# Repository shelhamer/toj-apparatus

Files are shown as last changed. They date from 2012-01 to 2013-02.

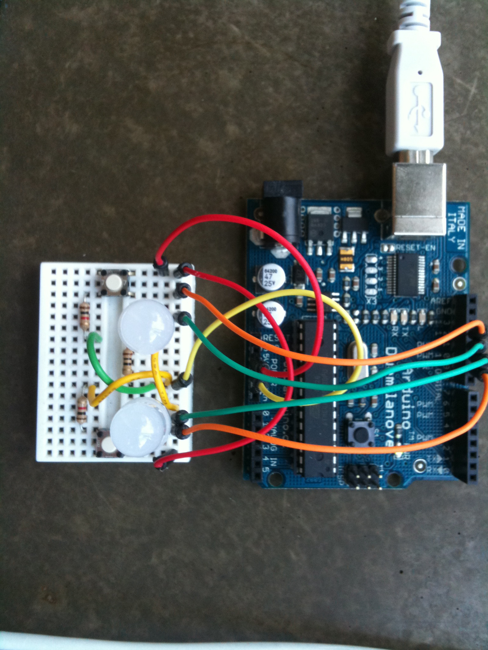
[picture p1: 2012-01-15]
toj-apparatus-top.jpg

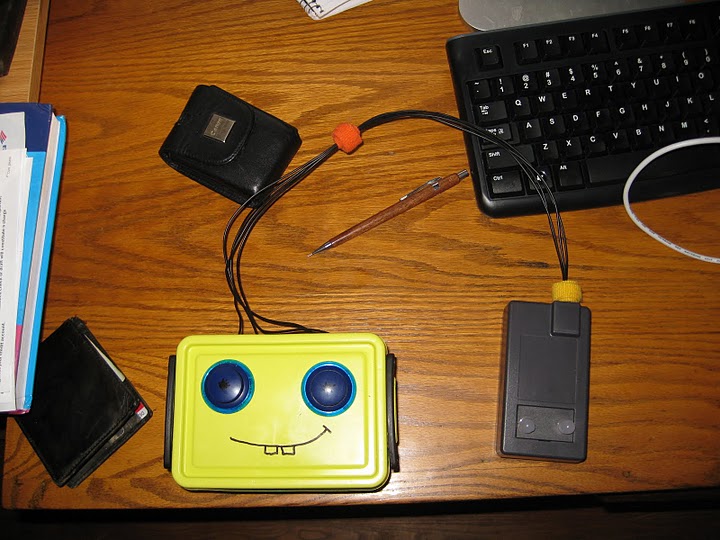
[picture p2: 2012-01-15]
toj-apparatus-case.jpg

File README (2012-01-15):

Time Order Judgement (TOJ) Apparatus & Controller

A novel apparatus for presenting visual light pulses and recording time order
judgements with subject response time. ~1 millisecond precision in both light
presentation and response time measurement. Assembled with simple electronic
components on a breadboard connected to an Arduino Duemilanove, programmed in
Arduino, and interfaced to a computer via serial to a Processing app.

Time order judgements concern the evaluation and decision of the relative
ordering of a series of events. In this case, the apparatus has two diffuse
white LEDs that can be pulsed with precision of < 1 ms. Five types of pulse
pairs are possible:

*  >  * left on, right on, left off, right off
* --> * left on, left off, right on, right off
*  <  * the first with direction reversed
* <-- * the second with direction reversed
*  =  * both on on simultaneously

The delay between the onset of one pulse after the other is determined by
pulse pair definitions which are triggered by the apparatus controller running
on a computer.

The apparatus is necessary because the careful presentation of stimuli in time
is complicated by computer monitor refresh rates and time resolution is
inadequate for the short delays tested in time order judgement experiments.

Within a certain time threshold, an observer will see a sequence of two
pulses as one single, simultaneous pulse. This is similar to the echo threshold
and precedence effect in psychoacoustics: if the same sound signal arrives at
an observer at different times within a certain window, only the direction of
the first arrival is perceived. The curious can read more here:

http://murphylibrary.uwlax.edu/digital/journals/JASA/JASA1999/pdfs/vol_106/iss_4/1633_1.pdf

The apparatus and controller were designed, assembled, and programmed by Evan
Shelhamer. The idea for the apparatus and the specific experimental stimuli
light pulse patterns are due to Patrick Taylor, PhD student in the neuroscience
and behavior and cognitive divisions of UMass Amherst Psychology.

TimeOrderApparatus: arduino project for running the device itself. Presents
visual flashes through LEDs, accepts push button responses, and communicates
over serial.

TimeOrderController: processing.org project for running experiments with the
apparatus. Reads stimulus sequence files, commands the apparatus, and
records responses and reaction times collected from apparatus to CSV.

Refer to photos for an idea of its construction. A bill of materials and
circuit diagram will be included once prepared.

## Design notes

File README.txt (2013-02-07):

Time Order Judgement (TOJ) Apparatus & Controller

A novel apparatus for presenting visual light pulses and recording time order
judgements with subject response time. ~1 millisecond precision in both light
presentation and response time measurement. Assembled with simple electronic
components on a breadboard connected to an Arduino Duemilanove, programmed in
Arduino, and interfaced to a computer via serial to a Processing app.

Time order judgements concern the evaluation and decision of the relative
ordering of a series of events. In this case, the apparatus has two diffuse
white LEDs that can be pulsed with precision of < 1 ms. Five types of pulse
pairs are possible:

*  >  * left on, right on, left off, right off
* --> * left on, left off, right on, right off
*  <  * the first with direction reversed
* <-- * the second with direction reversed
*  =  * both on on simultaneously

The delay between the onset of one pulse after the other is determined by
pulse pair definitions which are triggered by the apparatus controller running
on a computer.

The apparatus is necessary because the careful presentation of stimuli in time
is complicated by computer monitor refresh rates and time resolution is
inadequate for the short delays tested in time order judgement experiments.

Within a certain time threshold, an observer will see a sequence of two
pulses as one single, simultaneous pulse. This is similar to the echo threshold
and precedence effect in psychoacoustics: if the same sound signal arrives at
an observer at different times within a certain window, only the direction of
the first arrival is perceived. The curious can read more here:

http://murphylibrary.uwlax.edu/digital/journals/JASA/JASA1999/pdfs/vol_106/iss_4/1633_1.pdf

The apparatus and controller were designed, assembled, and programmed by Evan
Shelhamer. The idea for the apparatus and the specific experimental stimuli
light pulse patterns are due to Patrick Taylor, PhD student in the neuroscience
and behavior and cognitive divisions of UMass Amherst Psychology.

TimeOrderApparatus: arduino project for running the device itself. Presents
visual flashes through LEDs, accepts push button responses, and communicates
over serial.

TimeOrderController: processing.org project for running experiments with the
apparatus. Reads stimulus sequence files, commands the apparatus, and
records responses and reaction times collected from apparatus to CSV.

To make your own:

- Check the bill of materials.
- Consult the schematic and breadboard images for wiring.
- Refer to photos for an idea of its construction.
- Install the Arduino toolkit to load the software to the device.
- Install the Processing.org toolkit to run the experiment controller.

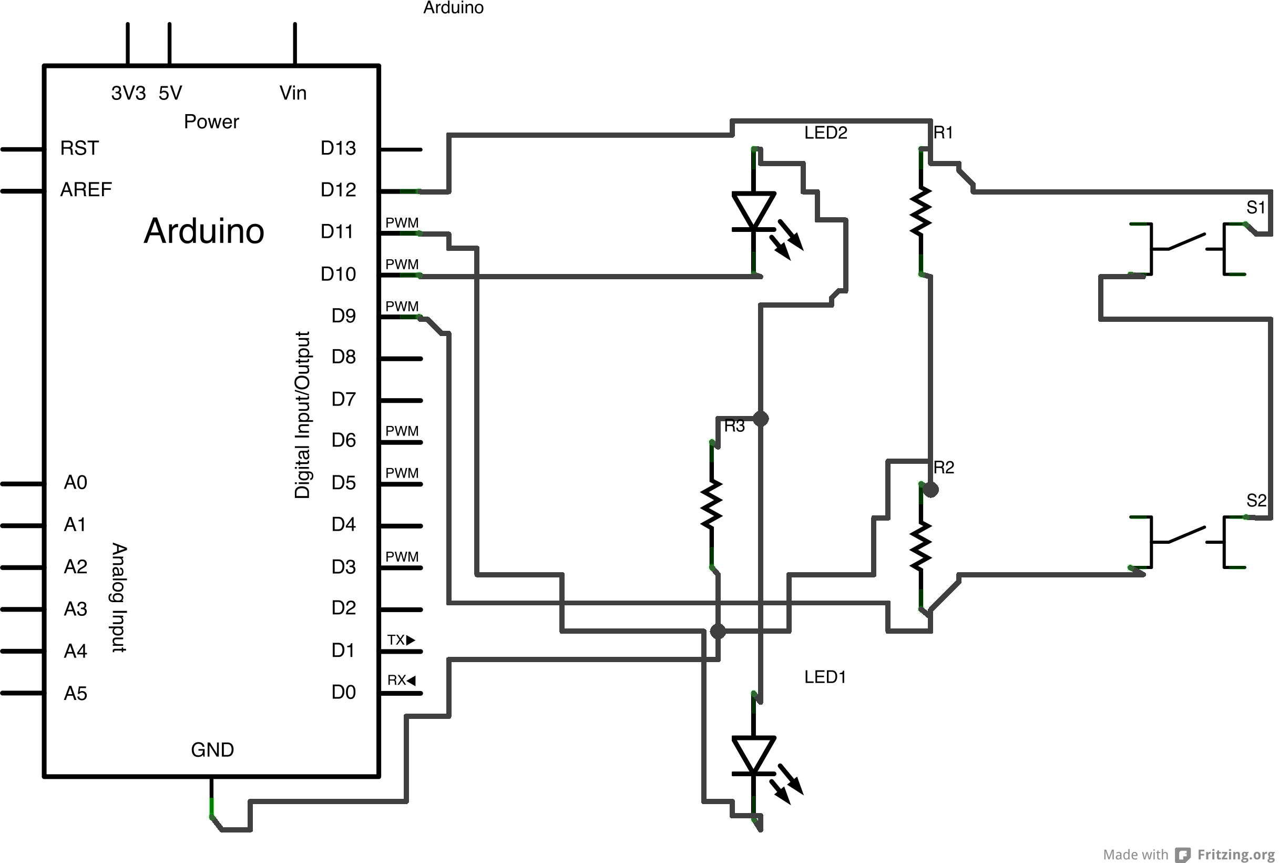
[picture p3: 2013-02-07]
schematic.png

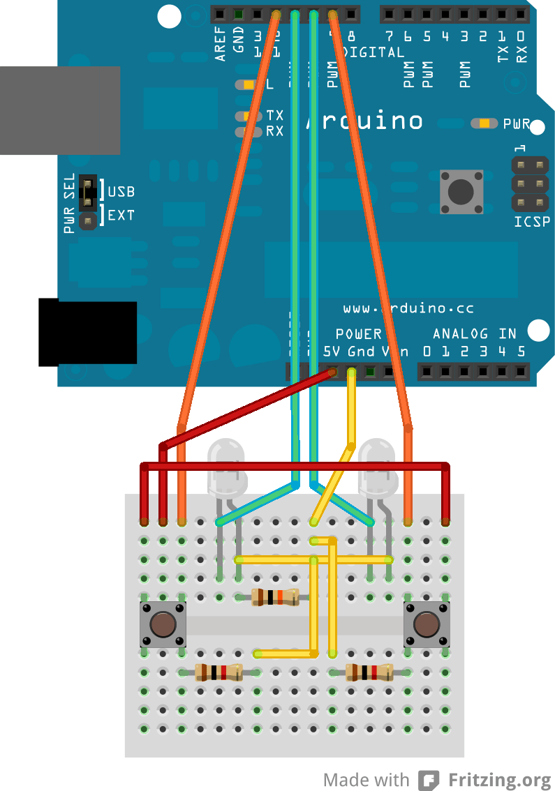
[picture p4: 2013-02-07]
breadboard.png

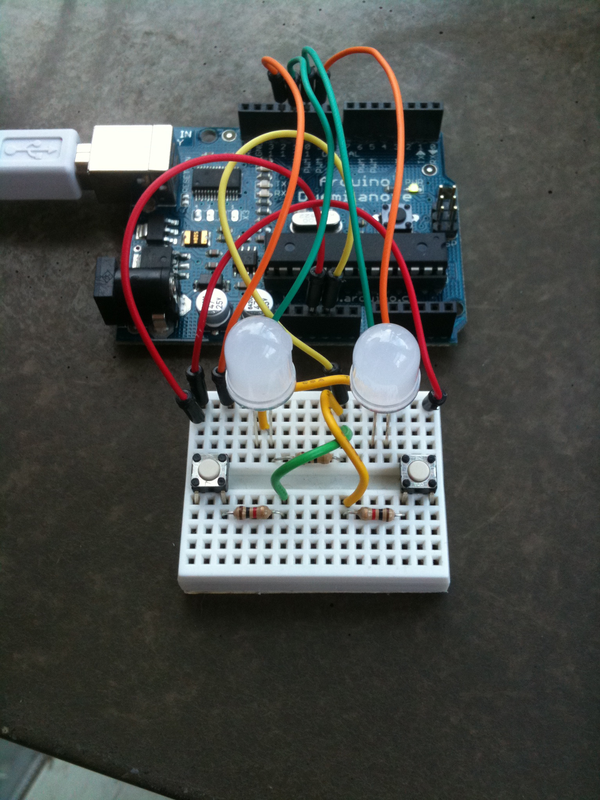
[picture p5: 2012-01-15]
toj-apparatus.jpg

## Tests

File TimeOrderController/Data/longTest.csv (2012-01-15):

Pulse | Side | ReactionTime
00 | L | 1056
15 | L | 600
15 | R | 1066
04 | L | 700
00 | R | 684
00 | R | 537
00 | R | 1011
15 | R | 471
19 | R | 1010
00 | R | 1204
15 | R | 724
15 | L | 1014
15 | R | 814
00 | R | 1569
15 | R | 918
00 | R | 458
04 | R | 471
19 | R | 494
04 | R | 660
19 | R | 458
15 | L | 1328
00 | R | 719
15 | R | 1408
15 | L | 733
15 | R | 897
00 | R | 1099
04 | R | 628
19 | R | 1546
00 | R | 915
00 | L | 857
00 | L | 593
15 | L | 1270
15 | L | 748
19 | R | 1215
04 | L | 498
15 | L | 662
15 | R | 722
00 | R | 1134
15 | R | 909
04 | R | 674
00 | L | 815
15 | R | 688

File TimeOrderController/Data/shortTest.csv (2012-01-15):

Pulse | Side | ReactionTime
01 | L | 389
02 | L | 427
09 | L | 397
26 | R | 359
03 | L | 873
08 | L | 705

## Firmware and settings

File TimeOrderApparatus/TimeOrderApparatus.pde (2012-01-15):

/**
 * Time Order Judgement (TOJ) Apparatus
 *
 * Present time light pulses through LEDs, identify button press responses,
 * accepting pulse commands and returning responses over serial.
 * Developed for Patrick Taylor in the NeuroCognition and Perception (NCaP) lab
 * UMass Amherst
 *
 * Evan Shelhamer. Fall '10.
 */

/* CONSTANTS */

// LEDs, left or right
#define LED_L 11
#define LED_R 10

// Buttons
#define BUTTON_R 9
#define BUTTON_L 12

// Duration of LED lighting, total # of pulses, sequence length
#define DUR 15
#define NUM_PULSE 30

// Pulse array indices
#define LED 0
#define DELAY 1

/* PULSE DEFINITIONS */

// Defined as 1st LED to light, and delay until 2nd
// N.B. Pulses defined by Patrick Taylor
long pulses[NUM_PULSE][2] = {
  {LED_L, 3}, //0
  {LED_L, 6}, //1
  {LED_L, 9}, //2
  {LED_L, 12}, //3
  {LED_L, 15}, //4
  {LED_L, 18}, //5
  {LED_L, 21}, //6
  {LED_L, 24}, //7
  {LED_L, 27}, //8
  {LED_L, 30}, //9
  {LED_L, 33}, //10
  {LED_L, 36}, //11
  {LED_L, 39}, //12
  {LED_L, 42}, //13
  {LED_L, 45}, //14
  {LED_R, 3}, //15
  {LED_R, 6}, //16
  {LED_R, 9}, //17
  {LED_R, 12}, //18
  {LED_R, 15}, //19
  {LED_R, 18}, //20
  {LED_R, 21}, //21
  {LED_R, 24}, //22
  {LED_R, 27}, //23
  {LED_R, 30}, //24
  {LED_R, 33}, //25
  {LED_R, 36}, //26
  {LED_R, 39}, //27
  {LED_R, 42}, //28
  {LED_R, 45} //29
};

void setup() {
  // Initialize LED pins to output & off state
  pinMode(LED_L, OUTPUT);
  pinMode(LED_R, OUTPUT);
  digitalWrite(LED_L, LOW);
  digitalWrite(LED_R, LOW);

  // Initialize button pins for input
  pinMode(BUTTON_L, INPUT);
  pinMode(BUTTON_R, INPUT);

  // Open serial communication
  Serial.begin(9600);
}

void loop() {
  int cur_pulse = -1; // pulse to perform (signalled over serial)

  // Wait for serial message (single byte indicating pulse index), check valid
  while (Serial.available() == 0);
  cur_pulse = (int) Serial.read();
  if (!(cur_pulse >= 0 && cur_pulse < NUM_PULSE))
    return;

  // LED blink order & timing
  int led = pulses[cur_pulse][LED];
  int other = (led == LED_L) ? LED_R : LED_L;
  int delay_time = pulses[cur_pulse][DELAY];

  // Pause before stimulus presentation
  delay(1000);

  // Record start time (in milliseconds), declare event/reaction timekeeping var
  unsigned long start_ms = millis();
  unsigned long now_ms;

  // Calculate event timings
  unsigned long led1off = start_ms + DUR;
  unsigned long led2on = start_ms + delay_time;
  unsigned long led2off = led2on + DUR;

  // perform light pulse & wait for subject response (button press)
  boolean button_l, button_r; button_l = button_r = false;
  while (!(button_l || button_r)) {
    // Abort if serial message received
    if (Serial.available() > 0)
      return;

     now_ms = millis(); // current time in milliseconds

    // Light 1st LED for allotted duration
    if (now_ms <= led1off)
      digitalWrite(led, HIGH);
    else
      digitalWrite(led, LOW);

    // Light 2nd LED during allotted time frame
    if (led2on <= now_ms && now_ms <= led2off)
      digitalWrite(other, HIGH);
    else
      digitalWrite(other, LOW);

    // Check button state
    button_l = digitalRead(BUTTON_L);
    button_r = digitalRead(BUTTON_R);
  }

  // Send results to host computer: button, reaction time
  if (cur_pulse < 10) { Serial.print('0'); }
  Serial.print(cur_pulse);
  Serial.print((button_l) ? 'L' : 'R');
  Serial.println(now_ms - start_ms);

  // Turn off LEDs to prepare next pulse
  digitalWrite(LED_L, LOW);
  digitalWrite(LED_R, LOW);
}

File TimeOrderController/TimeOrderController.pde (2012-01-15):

/**
 * Time Order Judgement (TOJ) Controller
 *
 * Trigger light pulse stimuli in apparatus, collect and record button responses
 * Developed for Patrick Taylor in the NeuroCognition and Perception (NCaP) lab
 * UMass Amherst
 *
 * Evan Shelhamer. Fall '10.
 */

import java.util.Scanner;
import java.util.LinkedList;
import java.io.FileWriter;
import java.io.IOException;

import processing.serial.*;

// Serial connection & port ID
Serial port;
final int PORT_NUM = 0; // ATTENTION: needs to be configured, see note below

/* Initialization */
void setup() {
  // Pulse sequence to execute, subject responses to record
  LinkedList seq;
  LinkedList resp;

  // List all the available serial ports on startup
  // Inspect list to look for apparatus connection...
  // ...and set PORT_NUM above to its order (counting from 0 for the 1st)
  println(Serial.list());

  // Open serial communication channel at 9600 baud speed
  port = new Serial(this, Serial.list()[PORT_NUM], 9600);

  // Disable graphics
  noLoop();

  // Keep running until user cancels or quits
  while(true) {
    /* SELECT INPUT SEQUENCE */
    try {
      seq = loadSequence(selectInput());
    }
    catch (FileNotFoundException e) {
      System.out.println("FILE NOT FOUND - PLEASE MAKE SURE THE SELECTED FILE EXISTS AND IS ACCESSIBLE");
      continue;
    }

    /* PRESENT SEQUENCE TO SUBJECT */
    resp = presentSequence(seq);

    /* RECORD RESULTS */
    boolean saved = false;
    while (!saved) { // keep trying until save successful to avoid data loss
      try {
        saved = saveResponses(selectOutput(), resp);
      }
      catch (IOException e) {
        System.out.println("COULD NOT SAVE FILE");
        System.exit(-1);
      }
    }
  }

  // HACK (unreachable code) System.out.println("Exiting...");
}

/* Load pulse sequences for transmission to apparatus */
LinkedList loadSequence(String filepath) throws FileNotFoundException {
  if (filepath == null)
    System.exit(0); // quit if no file is selected

  // Create scanner and configure for reading CSV
  Scanner sc = new Scanner(new File(filepath));
  sc.useDelimiter(",");

  // Create linked list and populate with pulse indices from file
  LinkedList fileSeq = new LinkedList();

  while(sc.hasNext()) {
    fileSeq.addFirst(sc.nextInt());
  }
  sc.close();

  System.out.println("Loaded " + filepath + "...");

  return fileSeq;
}

/* Present sequence by sending it to apparatus, one pulse at a time */
LinkedList presentSequence(LinkedList seq) {
  // for accumulating responses
  LinkedList resps = new LinkedList();

  // Iterate over each pulse in the sequence, sending each pulse
  // to the apparatus and waiting for the response recorded
  int cur_pulse = 1;
  int pulse_len = seq.size();
  while (seq.size() != 0) {
    Integer pulse_index = (Integer) seq.removeFirst();

    // Send pulse index (maps to a pulse coded onto apparatus)
    port.write(pulse_index);
    System.out.println("Sent " + cur_pulse + " of " + pulse_len + " pulses");

    // Keep trying to read response until complete (terminated by newline)
    String respStr = "";
    while (true) {
      if (port.available() > 0) {
        respStr += port.readString();
        if (respStr.charAt(respStr.length()-1) == '\n')
          break;
      }

      delay(10);
    }

    // Read entire response and store in response array
   resps.addFirst(respStr.trim());

   cur_pulse++;
  }

  return resps;
}

/* Save responses to text file (CSV) */
boolean saveResponses(String filepath, LinkedList resps) throws IOException {
  // Retry if no output file specified
  if (filepath == null)
    return false;

  // Open output file and write CSV header
  FileWriter out = new FileWriter(filepath);
  out.append("Pulse,Side,ReactionTime\n");

  // Iterate over each response and save to file
  while (resps.size() != 0) {
    // Pull off from list and split
    // into side (left/right) and reaction time (milliseconds)
    String respString = (String) resps.removeFirst();
    String pulse = respString.substring(0,2);
    String side = respString.substring(2,3);
    String time = respString.substring(3);


    // Output side & reaction time, comma-separated
    out.append(pulse + "," + side + "," + time + "\n");
  }

  // Flush & close output to finish saving
  out.flush();
  out.close();

  System.out.println("Saved results to " + filepath);

  return true;
}

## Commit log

2012-01-15 Time Order Judgement (TOJ) apparatus
    A novel apparatus for biophysics experiments investigating time order
    judgements. These are judgements about the perception of the order of events.
    In particular, this apparatus presents pairs of LED pulses and records a
    research participant's judgement of the order of the pulses and reaction time.
    Temporal precision is within 1 ms.
    Included here is:
    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
    [longTest.csv, shortTest.csv]
2013-02-02 Add bill of materials
2013-02-07 Add circuit project, breadboard & schematic images; rename images
    [toj-apparatus-circuit.fzz]
